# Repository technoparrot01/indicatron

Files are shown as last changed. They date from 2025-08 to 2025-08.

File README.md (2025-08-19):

# INDICATRON
Display/Clock with 100 4bit seven-segment 0.28 Inch indicators, RTC and Wi-Fi support.

Project is separated into two PCBs for modular design.\
Requires a 9–12V / 5A power supply.

[Bad apple on this](https://youtu.be/aoGiHarBVdQ)

# Animation example:
Preview

# Pictures:
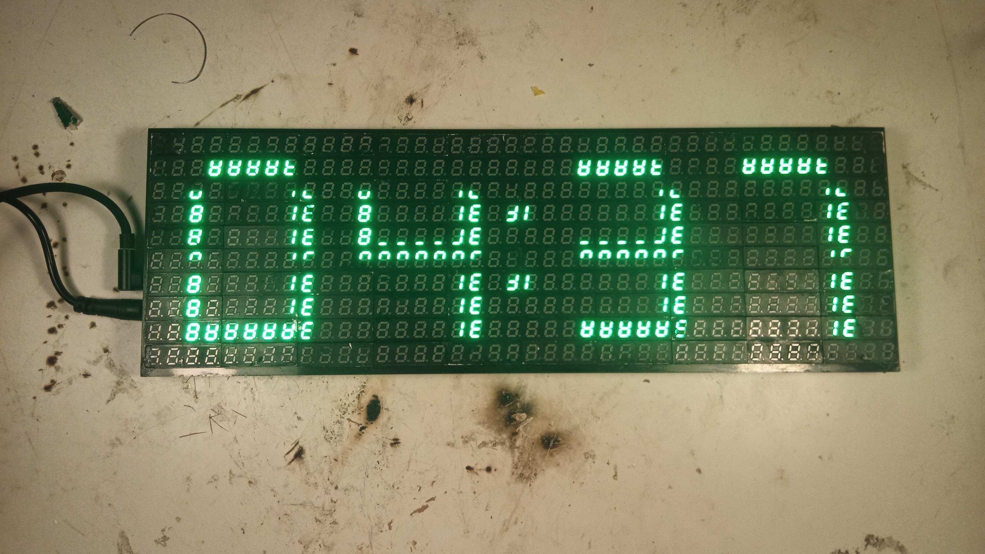
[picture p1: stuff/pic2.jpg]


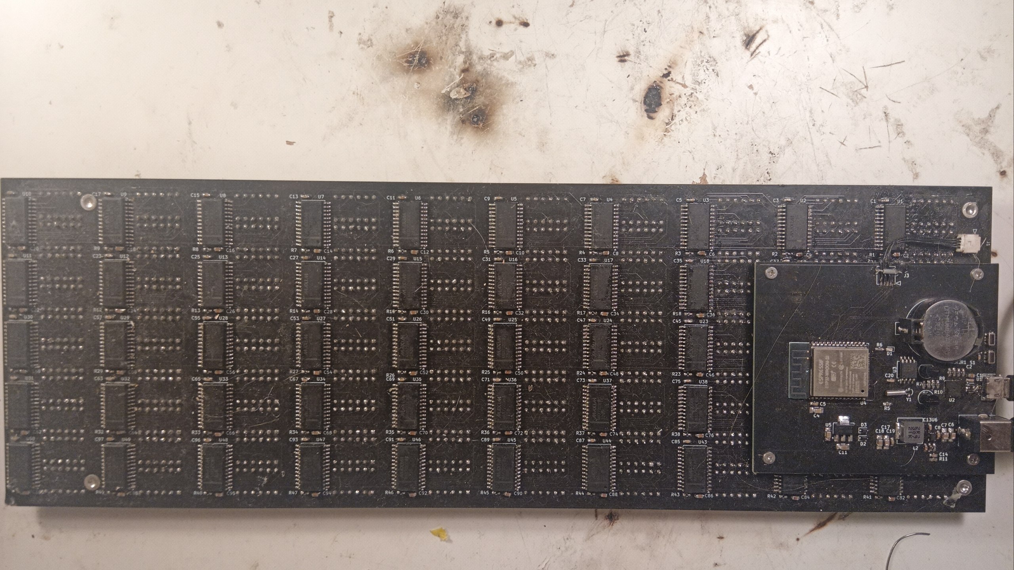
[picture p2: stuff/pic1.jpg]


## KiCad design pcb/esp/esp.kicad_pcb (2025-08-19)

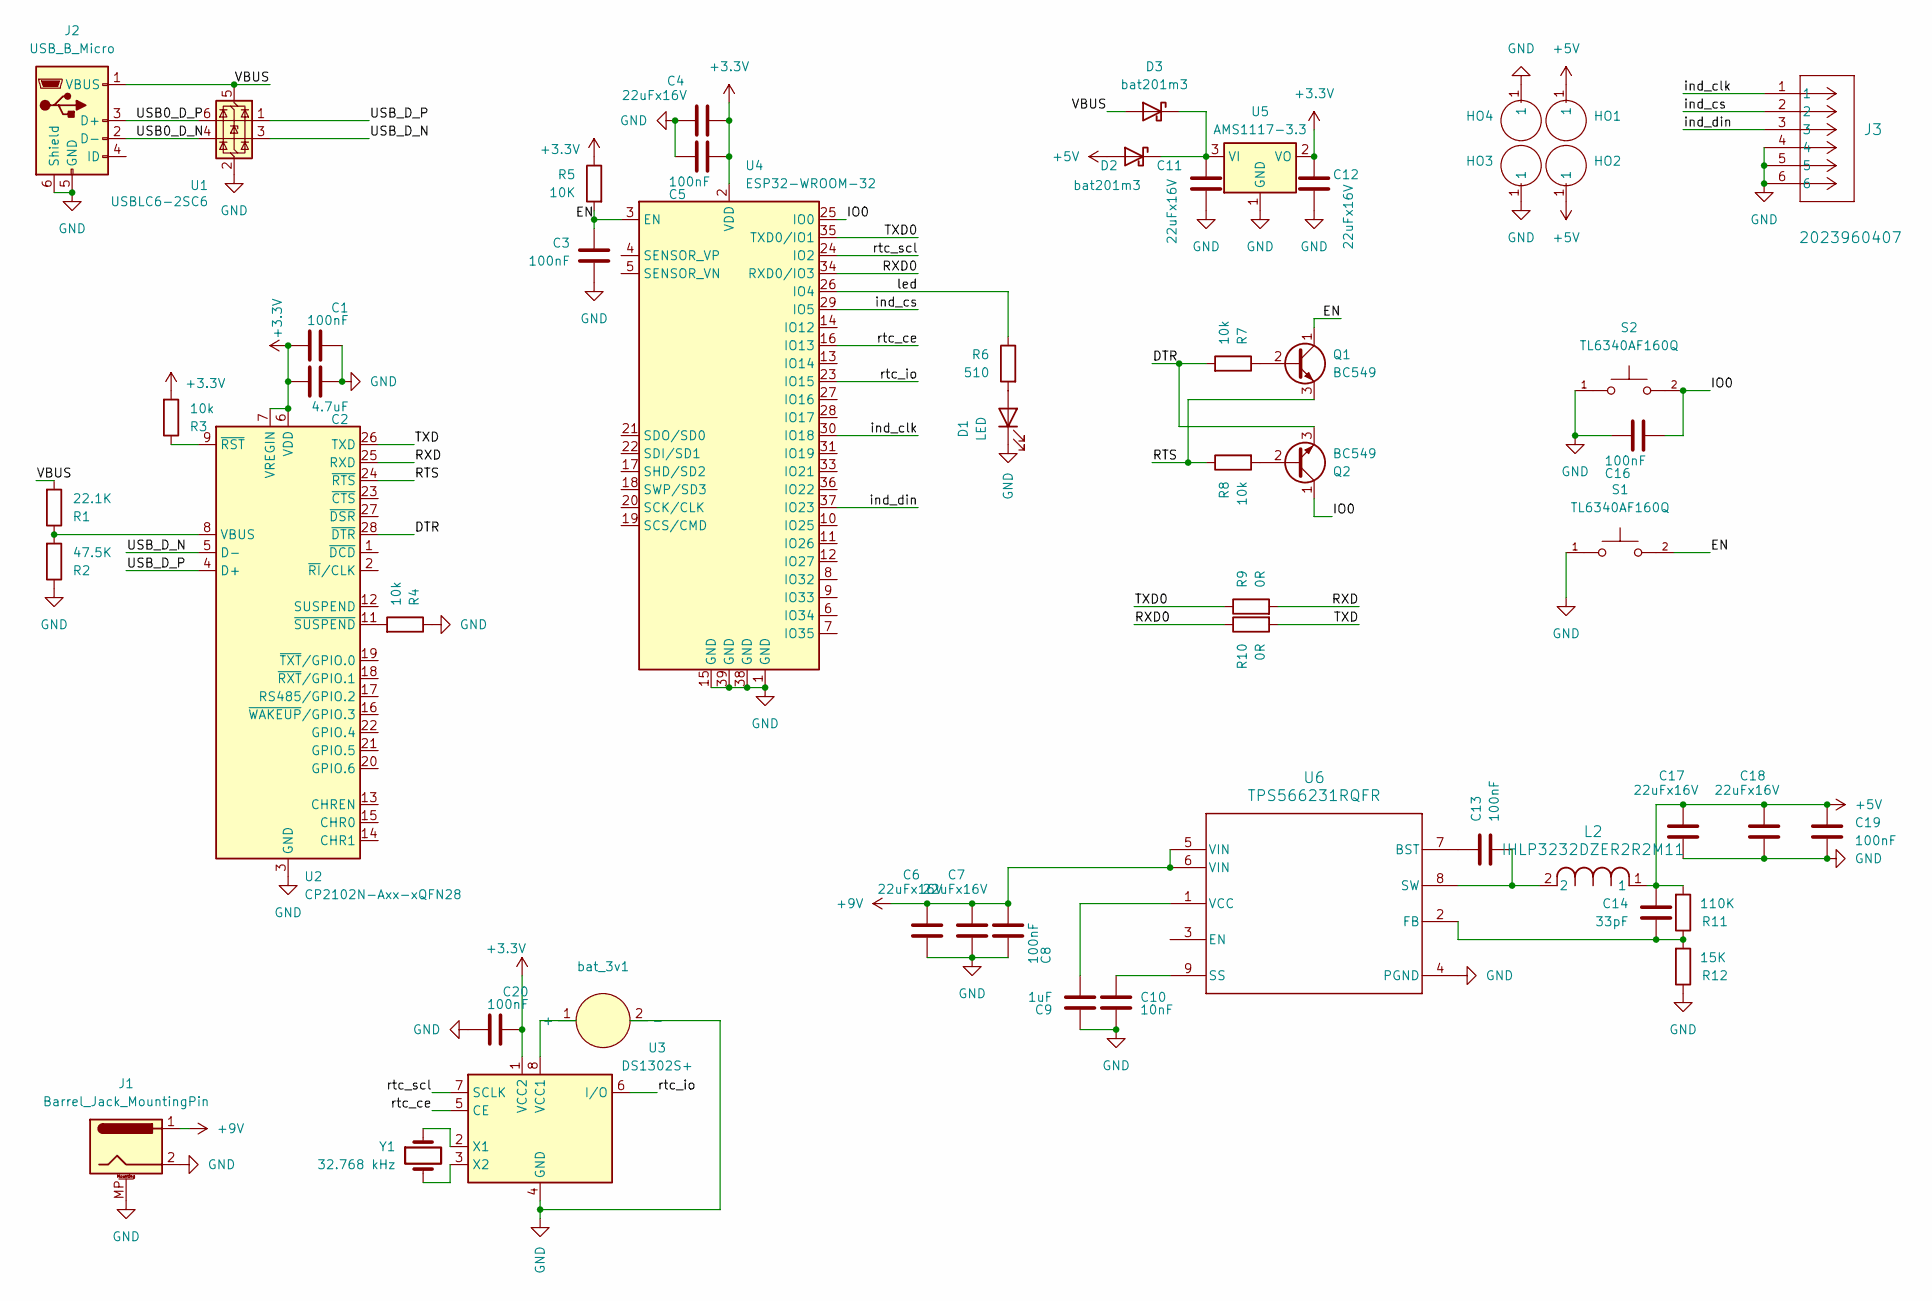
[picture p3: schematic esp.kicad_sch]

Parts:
C1, C3, C5, C8, C13, C16, C19, C20: 100nF; C_0603_1608Metric_Pad1.08x0.95mm_HandSolder
C2: 4.7uF; C_0603_1608Metric_Pad1.08x0.95mm_HandSolder
C4, C6, C7, C11, C12, C17, C18: 22uFx16V; C_1206_3216Metric_Pad1.33x1.80mm_HandSolder
C9: 1uF; C_0603_1608Metric_Pad1.08x0.95mm_HandSolder
C10: 10nF; C_0603_1608Metric_Pad1.08x0.95mm_HandSolder
C14: 33pF; C_0603_1608Metric_Pad1.08x0.95mm_HandSolder
D1: LED; LED_0603_1608Metric
D2, D3: bat201m3; D_SOD-323F
HO1, HO2, HO3, HO4: 9774030243R_HOLE
J1: Barrel_Jack_MountingPin; BarrelJack_CUI_PJ-063AH_Horizontal
J2: USB_B_Micro; USB_Micro-B_Amphenol_10118193-0002LF_Horizontal
J3: 2023960407; CON_2023960407
L2: IHLP3232DZER2R2M11; IND_IHLP-3232DZ_VIS
Q1, Q2: BC549; TO-92_Inline
R1: 22.1K; R_0603_1608Metric_Pad0.98x0.95mm_HandSolder
R2: 47.5K; R_0603_1608Metric_Pad0.98x0.95mm_HandSolder
R3, R4, R7, R8: 10k; R_0603_1608Metric_Pad0.98x0.95mm_HandSolder
R5: 10K; R_0603_1608Metric_Pad0.98x0.95mm_HandSolder
R6: 510; R_0603_1608Metric_Pad0.98x0.95mm_HandSolder
R9, R10: 0R; R_0603_1608Metric_Pad0.98x0.95mm_HandSolder
R11: 110K; R_0603_1608Metric_Pad0.98x0.95mm_HandSolder
R12: 15K; R_0603_1608Metric_Pad0.98x0.95mm_HandSolder
S1, S2: TL6340AF160Q; SW_TL6340AF160Q; PARTREV 10.23.2019
U1: USBLC6-2SC6; SOT-23-6
U2: CP2102N-Axx-xQFN28; QFN-28-1EP_5x5mm_P0.5mm_EP3.35x3.35mm
U3: DS1302S+; SO-8_5.3x6.2mm_P1.27mm
U4: ESP32-WROOM-32
U5: AMS1117-3.3; SOT-223-3_TabPin2
U6: TPS566231RQFR; RQF0009A
Y1: 32.768 kHz; Crystal_Round_D2.0mm_Vertical
bat_3v1: Battery_CR2032_3v_holder

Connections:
+3.3V: C1.1, C2.1, C4.1, C5.1, C12.1, C20.2, R3.2, R5.1, U2.6 (VDD), U2.7 (VREGIN), U3.1 (VCC2), U4.2 (VDD), U5.2 (VO)
+5V: C14.1, C17.1, C18.1, C19.1, D2.2 (A), HO1.1, HO2.1, L2.1, R11.2
+9V: C6.1, C7.1, C8.1, J1.1, U6.5 (VIN), U6.6 (VIN)
/DTR: Q2.3 (E), R7.2, U2.28 (~DTR)
/EN: C3.1, Q1.1 (C), R5.2, S1.2, U4.3 (EN)
/IO0: C16.1, Q2.1 (C), S2.2, U4.25 (IO0)
/RTS: Q1.3 (E), R8.1, U2.24 (~RTS)
/RXD: R9.2, U2.25 (RXD)
/RXD0: R10.1, U4.34 (RXD0/IO3)
/TXD: R10.2, U2.26 (TXD)
/TXD0: R9.1, U4.35 (TXD0/IO1)
/USB0_D_N: J2.2 (D-), U1.4 (I/O2)
/USB0_D_P: J2.3 (D+), U1.6 (I/O1)
/USB_D_N: U1.3 (I/O2), U2.5 (D-)
/USB_D_P: U1.1 (I/O1), U2.4 (D+)
/VBUS: D3.2 (A), J2.1 (VBUS), R1.2, U1.5 (VBUS)
/ind_clk: J3.1, U4.30 (IO18)
/ind_cs: J3.2, U4.29 (IO5)
/ind_din: J3.3, U4.37 (IO23)
/led: R6.1, U4.26 (IO4)
/rtc_ce: U3.5 (CE), U4.16 (IO13)
/rtc_io: U3.6 (I/O), U4.23 (IO15)
/rtc_scl: U3.7 (SCLK), U4.24 (IO2)
GND: C1.2, C2.2, C3.2, C4.2, C5.2, C6.2, C7.2, C8.2, C9.2, C10.2, C11.2, C12.2, C16.2, C17.2, C18.2, C19.2, C20.1, D1.1 (K), HO3.1, HO4.1, J1.2, J1.MP (MountPin), J2.5 (GND), J2.6 (Shield), J3.4, J3.5, J3.6, R2.1, R4.1, R12.1, S1.1, S2.1, U1.2 (GND), U2.3 (GND), U2.29 (GND), U3.4 (GND), U4.1 (GND), U4.15 (GND), U4.38 (GND), U4.39 (GND), U5.1 (GND), U6.4 (PGND), bat_3v1.2 (-)
unnamed: D1.2 (A), R6.2
unnamed: C11.1, D2.1 (K), D3.1 (K), U5.3 (VI)
unnamed: Q1.2 (B), R7.1
unnamed: Q2.2 (B), R8.2
unnamed: R1.1, R2.2, U2.8 (VBUS)
unnamed: R3.1, U2.9 (~RST)
unnamed: R4.2, U2.11 (~SUSPEND)
unnamed: U3.8 (VCC1), bat_3v1.1 (+)
unnamed: U3.2 (X1), Y1.1
unnamed: U3.3 (X2), Y1.2
unnamed: C13.1, U6.7 (BST)
unnamed: C14.2, R11.1, R12.2, U6.2 (FB)
unnamed: C10.1, U6.9 (SS)
unnamed: C13.2, L2.2, U6.8 (SW)
unnamed: C9.1, U6.1 (VCC)

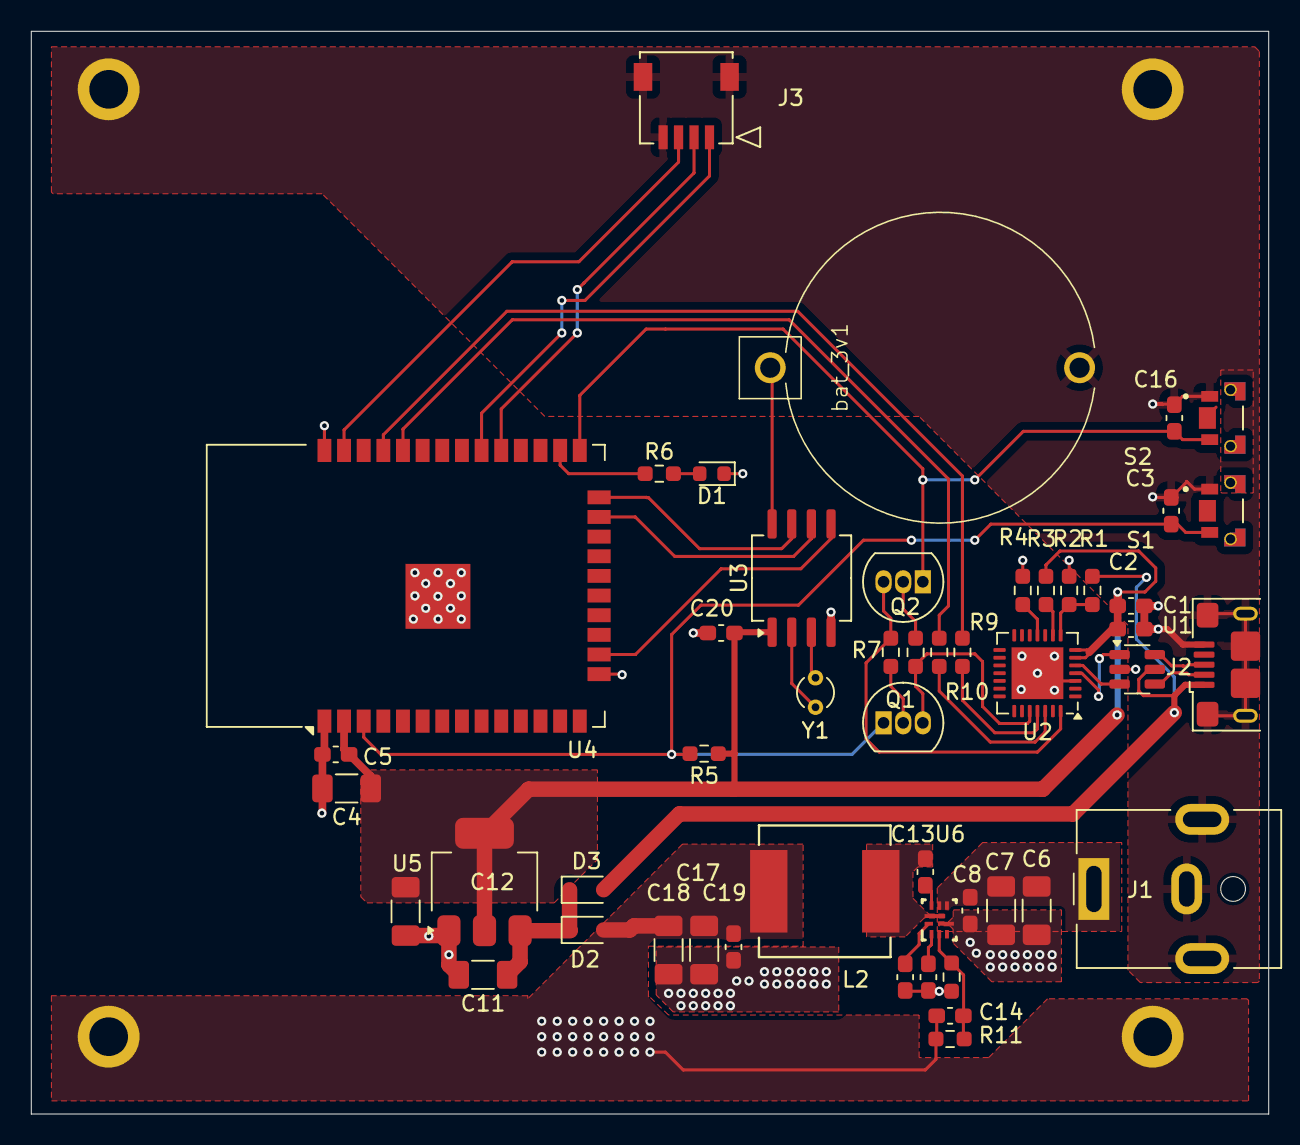
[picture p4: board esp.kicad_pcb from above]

Board: 2 copper layers, 80.0 x 70.0 mm, 54 parts (0 on the bottom side), 39 nets.

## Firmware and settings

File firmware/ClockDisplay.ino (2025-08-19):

#include "MAX7219.h"

#define MAX_CS 5
#define DW 10
#define DH 5

MaxDisp<MAX_CS, DW, DH> disp;

#include <ThreeWire.h>
#include <RtcDS1302.h>

#define DS1302_IO    15
#define DS1302_SCLK   2
#define DS1302_CE    13

ThreeWire myWire(DS1302_IO, DS1302_SCLK, DS1302_CE);
RtcDS1302<ThreeWire> Rtc(myWire);

void ensureRtcRunningAndValid() {
  Rtc.Begin();
  Rtc.SetIsWriteProtected(false);
  Rtc.SetIsRunning(true);
  if (!Rtc.IsDateTimeValid()) {
    RtcDateTime compiled(__DATE__, __TIME__);
    Rtc.SetDateTime(compiled);
  }
}

const uint8_t SEG_MAP[10] PROGMEM = {
  0b1111110,
  0b0110000,
  0b1101101,
  0b1111001,
  0b0110011,
  0b1011011,
  0b1011111,
  0b1110000,
  0b1111111,
  0b1111011
};

void segRect(int x, int y, int w, int h) {
  if (w <= 0 || h <= 0) return;
  for (int i = 0; i < h; i++) disp.line(x, y + i, x + w - 1, y + i);
}

void drawSegDigit(int x, int y, int w, int h, uint8_t digit, int t) {
  if (digit > 9) digit = 0;

  int pad = max(1, t);
  int ix = x + pad;
  int iy = y + pad;
  int iw = max(3 * t, w - 2 * pad);
  int ih = max(5 * t, h - 2 * pad);

  int A_w = iw - 2 * t;
  int A_h = t;
  int H_gap = t;

  int V_h = (ih - 3 * t) / 2;
  if (V_h < t) V_h = t;

  int leftX  = ix;
  int rightX = ix + iw - t;
  int midY   = iy + (ih - t) / 2;

  int Ax = ix + t, Ay = iy;
  int Gx = ix + t, Gy = midY;
  int Dx = ix + t, Dy = iy + ih - t;

  int Fx = leftX,  Fy = iy + t + H_gap;
  int Bx = rightX, By = iy + t + H_gap;
  int Ex = leftX,  Ey = midY + t + H_gap;
  int Cx = rightX, Cy = midY + t + H_gap;

  uint8_t mask = pgm_read_byte(&SEG_MAP[digit]);

  if (mask & 0b1000000) segRect(Ax, Ay, A_w, A_h);
  if (mask & 0b0100000) segRect(Bx, By, t, V_h);
  if (mask & 0b0010000) segRect(Cx, Cy, t, V_h);
  if (mask & 0b0001000) segRect(Dx, Dy, A_w, A_h);
  if (mask & 0b0000100) segRect(Ex, Ey, t, V_h);
  if (mask & 0b0000010) segRect(Fx, Fy, t, V_h);
  if (mask & 0b0000001) segRect(Gx, Gy, A_w, A_h);
}

void drawSegColon(int x, int y, int w, int h, int t, bool on) {
  if (!on) return;
  int dot = max(1, t);
  int cx = x + w / 2 - dot / 2;
  int topY = y + h / 3 - dot / 2;
  int botY = y + 2 * h / 3 - dot / 2;
  segRect(cx, topY, dot, dot);
  segRect(cx, botY, dot, dot);
}

void drawClockAuto(uint8_t hh, uint8_t mm, bool colonOn) {
  disp.clear();

  const int W = disp.W();
  const int H = disp.H();

  int marginX = max(1, W / 40);
  int marginY = max(1, H / 20);
  int colonW  = max(1, W / 24);
  int gap     = max(1, W / 80);

  int availableW = W - 2 * marginX - colonW - 5 * gap;
  int digitW = availableW / 4;
  int digitH = H - 2 * marginY;
  int t = max(1, min(digitW, digitH) / 8);

  int x0 = marginX;
  int y0 = marginY;

  uint8_t d0 = hh / 10;
  uint8_t d1 = hh % 10;
  uint8_t d2 = mm / 10;
  uint8_t d3 = mm % 10;

  drawSegDigit(x0, y0, digitW, digitH, d0, t);
  int x1 = x0 + digitW + gap;
  drawSegDigit(x1, y0, digitW, digitH, d1, t);
  int cx = x1 + digitW + gap;
  drawSegColon(cx, y0, colonW, digitH, t, colonOn);
  int x2 = cx + colonW + gap;
  drawSegDigit(x2, y0, digitW, digitH, d2, t);
  int x3 = x2 + digitW + gap;
  drawSegDigit(x3, y0, digitW, digitH, d3, t);

  disp.update();
}

void dvdBig() {
  const int W = max(12, disp.W() / 3);
  const int H = max(10, disp.H() / 3);

  static bool inited = false;
  static int x10, y10, vx, vy;

  if (!inited) {
    inited = true;
    x10 = ((disp.W() - W) / 2) * 10;
    y10 = ((disp.H() - H) / 2) * 10;
    vx = random(8, 14);
    vy = random(6, 12);
  }

  x10 += vx;
  y10 += vy;

  if (x10 <= 0) { x10 = 0; vx = -vx; }
  if (x10 >= (disp.W() - W) * 10) { x10 = (disp.W() - W) * 10; vx = -vx; }
  if (y10 <= 0) { y10 = 0; vy = -vy; }
  if (y10 >= (disp.H() - H) * 10) { y10 = (disp.H() - H) * 10; vy = -vy; }

  const int x = x10 / 10;
  const int y = y10 / 10;

  disp.clear();
  disp.line(x,         y,          x + W - 1, y);
  disp.line(x,         y,          x,         y + H - 1);
  disp.line(x + W - 1, y,          x + W - 1, y + H - 1);
  disp.line(x,         y + H - 1,  x + W - 1, y + H - 1);

  int s = 1;
  int maxS_w = (W - 6) / (3 * 5);
  int maxS_h = (H - 6) / 7;
  if (maxS_w > 1 && maxS_h > 1) s = min(maxS_w, maxS_h);

  disp.setScale(s);
  int textW = 3 * 5 * s;
  int textH = 7 * s;
  int tx = x + (W - textW) / 2;
  int ty = y + (H - textH) / 2;

  disp.setCursor(tx, ty);
  disp.print("DVD");

  disp.update();
  delay(10);
}

void clock_from_rtc() {
  static bool dots = false;
  static uint32_t lastBlink = 0;
  uint32_t nowMs = millis();
  if (nowMs - lastBlink >= 500) {
    lastBlink = nowMs;
    dots = !dots;
  }
  RtcDateTime now = Rtc.GetDateTime();
  uint8_t hh = now.Hour();
  uint8_t mm = now.Minute();
  drawClockAuto(hh, mm, dots);
}

void setup() {
  randomSeed(analogRead(0));
  disp.begin();
  disp.setBright(10);
  disp.textDisplayMode(GFX_ADD);
  ensureRtcRunningAndValid();
}

void loop() {
  //clock_from_rtc();
   dvdBig();
  delay(10);
}

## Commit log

2025-08-19 added gerber files
    [esp-B_Cu.gbr, esp-B_Mask.gbr, esp-B_Paste.gbr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]
2025-08-19 added pcb's
    [esp.kicad_pcb, esp.kicad_sch, indicator.kicad_sch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]
